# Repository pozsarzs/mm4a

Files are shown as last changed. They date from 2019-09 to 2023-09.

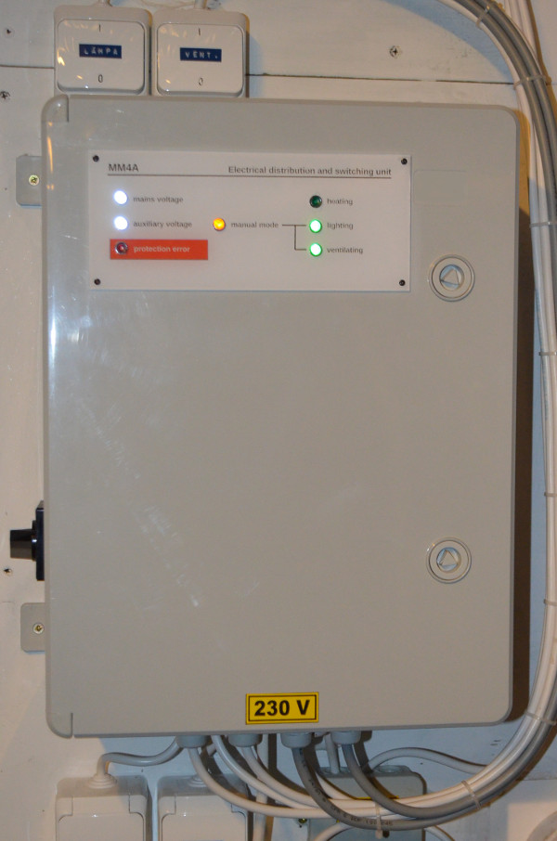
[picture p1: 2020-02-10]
pictures/mm4a.jpg

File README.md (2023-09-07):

**MM4A * Electrical distribution and switching unit for growing house**  
Copyright (C) 2019 Pozsár Zsolt <pozsarzs@gmail.com>  
Homepage: <http://www.pozsarzs.hu>  
GitHub: <https://github.com/pozsarzs/mm4a>

**Documentation**

- version:             1.0
- language:            en, hu
- licence:             CC-BY-NC-4.0

**Hardware**

 - version:            v190919

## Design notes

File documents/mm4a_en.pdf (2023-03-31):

## MM4A Electrical distribution and switching unit for growing house

### Technical manual

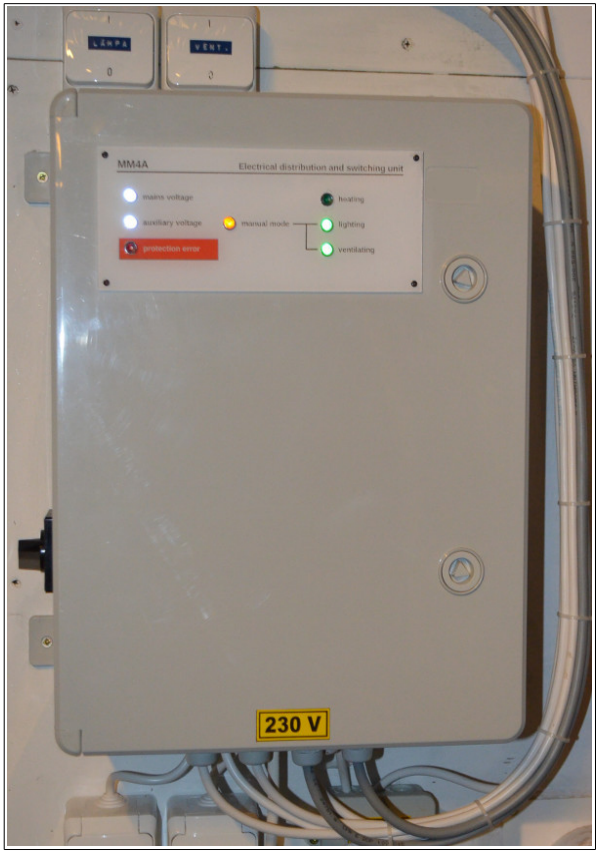
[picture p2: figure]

Hardware version: v190919
Technical manual version: v1.0 Issue date: 2019-09-19
Drawing number: 59/4/1-2

## CC-BY-NC-4.0

Technical manual | 2

Content

Technical manual | 3

## I. Equipment

Technical manual | 4

You can use this unit with MM3D or MM5D digital contol and remote device to switch heater, lighting and ventilating of growing house.

### 1. Technical data

Supply voltage: | 230 V AC 50/60 Hz
Auxiliary voltage: | 230 V AC
Max. supply current: | max. 16 A
Required protection: | 16 A fuse or overcurrent breaker
Isolation class: | Class I.
Mechanical size: | 300 x 400 x 170 mm
IP protection: | IP 54
IK protection: | IK 03
Material of cover: | termoplast (ABS)

Outputs

| Heating | Lighting | Ventilating | Outdoor lighting | Internal connector | Wall connector
Mode of ext. control* Max. output Protection of output Warning light of | with NO contact | | | overcurrent breaker | overcurrent breaker | overcurrent breaker
Contolled | yes | yes | yes | no | no | no
Manual control | no | yes | yes
External control | yes | yes | yes
Output voltage | 230 V AC | 230 V AC | 230 V AC | 230 V AC | 230 V AC | 230 V AC
current** | 10 A | 6 A | 6 A | 6 A | 6 A | 10 A
| overcurrent breaker | overcurrent breaker | overcurrent breaker
protection | yes | yes | yes | no | yes | no

* WARNING! There are 230 V AC between opened contacts!
**The value indicates the load capacity of a given branch, but the sum of the total output currents must not exceed the total current consumption of the device.

### 2. Description

a) Heating

The output of the channel is protected by a F4 circuit-breaker inside the cabinet, and its active status is indicated by the green LED marked Active. The channel cannot be operated manually, it can be

Technical manual | 5

activated by a short-circuit to its input. The external thermostat prevents overheating of the growing area due to a malfunction. The off contact disconnects the heaters from the mains (L-N).

The red light on the Protection error LED indicates overcurrent protection.

b) Lighting

The output of the channel is protected by an F5 circuit breaker inside the cabinet, and its active status is indicated by the green LED marked Active. The channel can be switched on manually and by a short circuit to its input. Manual mode is indicated by the yellow LED marked Manual mode. When the contactor is off, the lamps are disconnected from the mains (L-N).

The red light on the Protection error LED indicates overcurrent protection.

c) Ventilating

The output of the channel is protected by an F6 circuit breaker inside the cabinet, and its active status is indicated by the green LED marked Active. The channel can be switched on manually and by a short circuit to its input. Manual mode is indicated by the yellow LED marked Manual mode. When the contactor is off, the ventilators are disconnected from the mains (L-N).

The red light on the Protection error LED indicates overcurrent protection.

d) Outdoor lighting

The channel is used to supply the outside lighting of the growing house, this output is protected by a circuit breaker F1 located inside the cabinet.

e) Wall socket

The channel is used to power the wall socket inside the growing house, this output is protected by a circuit breaker F2 inside the cabinet.

f) Internal socket

The channel is used to supply the socket inside the enclosure and the control unit can be connected to it. The output is protected by F3 circuit breaker.

The red light on the Protection error LED indicates overcurrent protection.

### 3. Schematic and other drawings

The schematic of MM4A is shown in Annex 1, the wiring diagram is shown in Annex 2. This diagrams, drilling drawings and front foil can be downloaded from the developer / manufacturer's website as part of the complete documentation in a variety of formats.

### 4. Terms of use

Hardware documentation can be modified and/or redistributed under the Creativ Commons 4.0

Technical manual | 6

Attribution Non-Commercial (CC-BY-NC-4.0) License. You can read the full (English) text of the license online. (Refer to Chapter II for references.)

### 5. Look of the unit

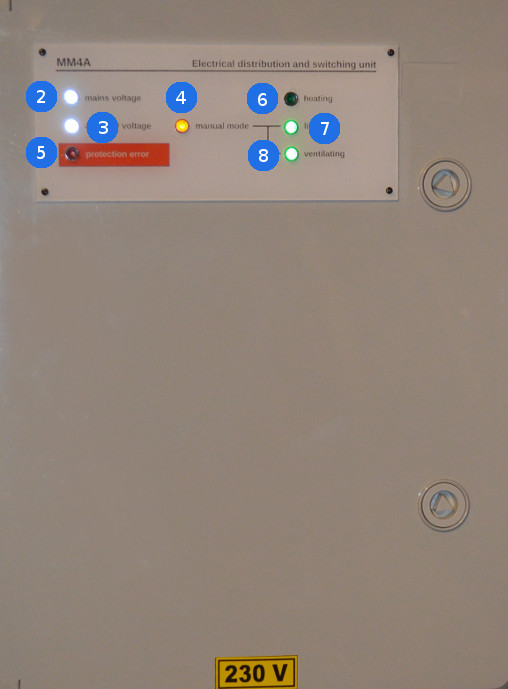
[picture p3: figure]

Figure 1: Front panel

Technical manual | 7
a) Manuals

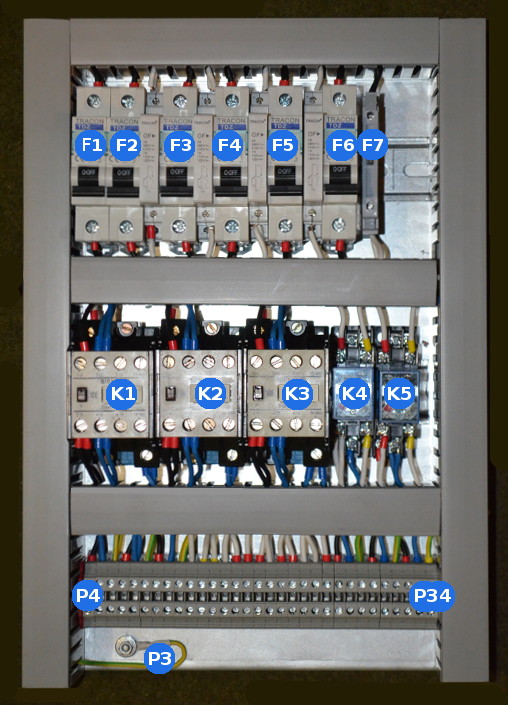
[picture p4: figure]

1: | Mains - Power switch
2: | Mains voltage - presence of mains voltage (white LED)
3: | Auxiliary voltage - the presence of auxiliary voltage (white LED)
4: | Manual mode - manual mode of lighting and ventilating (yellow LED)
5: | Protection error - status of overcurrent protection (red LED)
6: | Active - heater output is under voltage (green LED)
7: | Active - lighting output is under voltage (green LED)
8: | Active - ventilating output is under voltage (green LED)

Figure 2: Internal construction

Technical manual | 8
b) Connector pinout

P1: mains power - L (input terminal of power switch)
P2: mains power - N (input terminal of power switch)
P3: mains power - PE (screw connection on mounting plate) P4: outdoor lamp - L
P5: outdoor lamp - N
P6: outdoor lamp - PE
P7: wall socket - L
P8: wall socket - N
P9: wall socket - PE
P10: internal socket - L
P11: internal socket - N
P12: internal socket - PE
P13: signal output - common
P14: signal output - manual operation (NO relay contat) P15: signal output - protection error (NO relay contat) P16: heater control input - auxiliary voltage
P17: heater control input - from control unit
P18: heater control input - safety thermostat
P19: heater control input - safety thermostat
P20: lighting control input - auxiliary voltage
P21: lighting control input - manual switch
P22: lighting control input - from control unit and manual switch P23: ventilating control input - auxiliary voltage
P24: ventilating contol input - manual switch
P25: ventilating contol input - from control unit and manual switch P26: heater power output - L
P27: heater power output - N
P28: heater power output - PE
P29: lighting power output - L P30: lighting power output - N P31: lighting power output - PE P32: ventilating power output - L P33: ventilating power output - N P34: ventilating power output - PE

Technical manual | 9

### 6. Downloadable documentation

The complete hardware documentation can be downloaded from the manufacturer's website in a compressed file in .tar.gz format. (Refer to Chapter II for references.)

Name of package: mm4a-190919-1.0.tar.gz

Content of package - important files only:

mm4a
│
├───cad_files | | CAD files
│ | ├───connecting | | | connecting drawing (KiCAD)
│ | │ | connecting.pro | | | project file
│ | │ | connecting.sch | | | schematic
│ | │ | *.* | | | others
│ | │
│ | ├───drilling | | | drilling drawings (LibreCAD)
│ | │ | bottom.dxf | | | bottom of cover
│ | │ | front.dxf | | | front of cover
│ | │
│ | └───mm4a | | | MM4A unit (KiCAD)
│ | mm4a.pro | | project file
│ | mm4a.sch | | schematic
│ | *.* | | others
│
├───documents | | documentation
│ | drill_bottom.pdf | | drilling bottom of cover
│ | drill_front.pdf | | drilling front of cover
│ | manual-source.tar.gz | | source of manual
│ | mm4a_en.pdf | | Technical manual (EN)
│ | mm4a_hu.pdf | | Technical manual (HU)
│ | sch_connecting.pdf | | connection of unit
│ | sch_mm4a.pdf | | MM4A schematic
│
├───frontpage | | frontpage
│ | frontpage.eps | | frontpage
│ | frontpage.odg | | frontpage
│ | frontpage.svg | | frontpage
│ | preview.png | | preview of frontpage
│ | size.txt | | size of frontpage
│
├───pictures | pictures
│ | mm4a.jpg | look
│ | sch_connecting.svg | connection of unit
│ | sch_mm4a.svg | MM4A schematic
│
├───LICENCE | Terms of use (EN)
└───README | Short description (EN)

Technical manual | 10

## II. Related links

Technical manual | 11

### 1. Equipment

Full documentation | http://www.szerafingomba.hu/equipments/mm4a/mm4a-190919-1.0.tar.gz
Technical manual (EN) | http://www.szerafingomba.hu/equipments/mm4a/tech-manual-190919-1.0-en.pdf
Technical manual (HU) | http://www.szerafingomba.hu/equipments/mm4a/tech-manual-190919-1.0-hu.pdf

Schematic drawings:
MM4A (PDF) | http://www.szerafingomba.hu/equipments/mm4a/sch_mm4a.pdf
Connection (PDF) | http://www.szerafingomba.hu/equipments/mm4a/sch_mm4a-connecting.pdf

### 2. Terms of use

CC-BY-NC-4.0 (EN) | https://creativecommons.org/licenses/by-nc/4.0/legalcode
CC-BY-NC-4.0 (EN) | https://creativecommons.org/licenses/by-nc/4.0/
CC-BY-NC-4.0 (HU) | https://creativecommons.org/licenses/by-nc/4.0/deed.hu

### 3. Developer and manufacturer

Homepage | http://www.szerafingomba.hu
E-mail | info@szerafingomba.hu

Technical manual | 12

## III. Annexes

Technical manual | 13

### 1. Schematic drawings

1. MM4A schematic and list of materials
2. Connecting schematic and list of materials

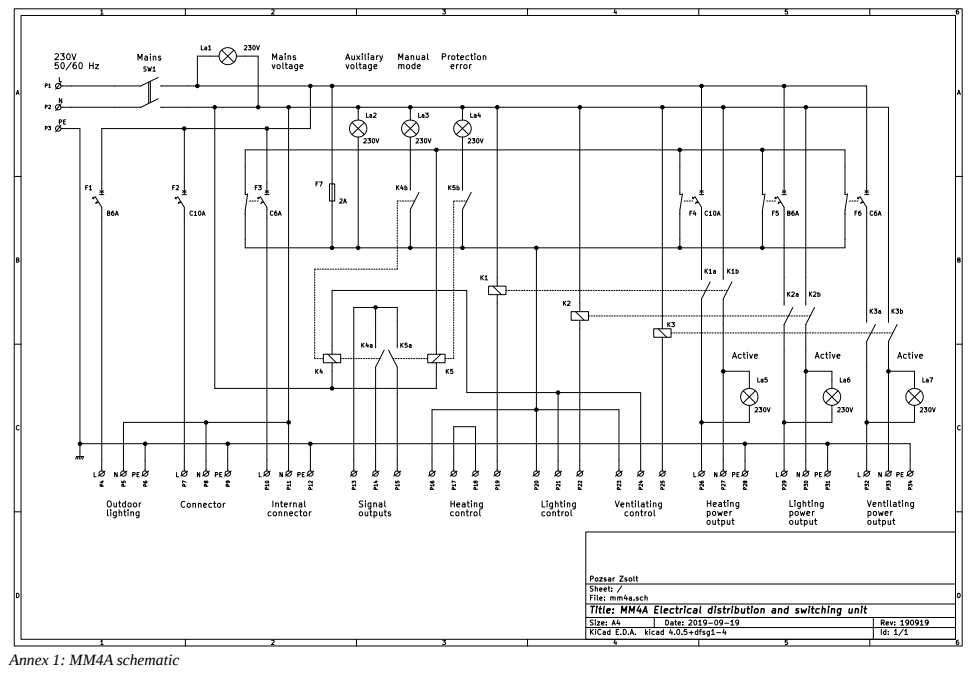
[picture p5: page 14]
Annex 1: MM4A schematic

List of materials

Pos. n. | Value | Description | Note | Pos. n. | Value | Description | Note
F1 | 6 A | overcurrent breaker B type | La5 | 230 V, green | signalling lamp
F2 | 10 A | overcurrent breaker C type | La6 | 230 V, green | signalling lamp
F3 | 6 A | overcurrent breaker C type | La7 | 230 V, green | signalling lamp
| 240 V/6 A | auxiliary contact | | P4-P34 | 0,5-6mm² | screw connectors
F4 | 10 A | overcurrent breaker C type | Sw1 | 250 V 16 A | two-pole switch
| 240 V/6 A | auxiliary contactor
F5 | 6 A | overcurrent breaker B type | 1 db | 300x400x170 | cabinet with mounting plate | ABS
| 240 V/6 A | auxiliary contact | | 2 m | 25x60 | wiring trunking
F6 | 6 A | overcurrent breaker C type | 1 m | 35 mm | mounting rail
| 240 V/6 A | auxiliary contact
F7 | 2 A | fuse
| 800 V/6,3 A | fuse holder
K1 | 230 V AC | contactor
K2 | 230 V AC | contactor | suitable for the load
K3 | 230 V AC | contactor
K4 | 230 V AC | relay | with two changeover
K5 | 230 V AC | contacts relay
La1 | 230 V, white | signalling lamp
La2 | 230 V, white | signalling lamp
La3 | 230 V, yellow | signalling lamp
La4 | 230 V, red | signalling lamp

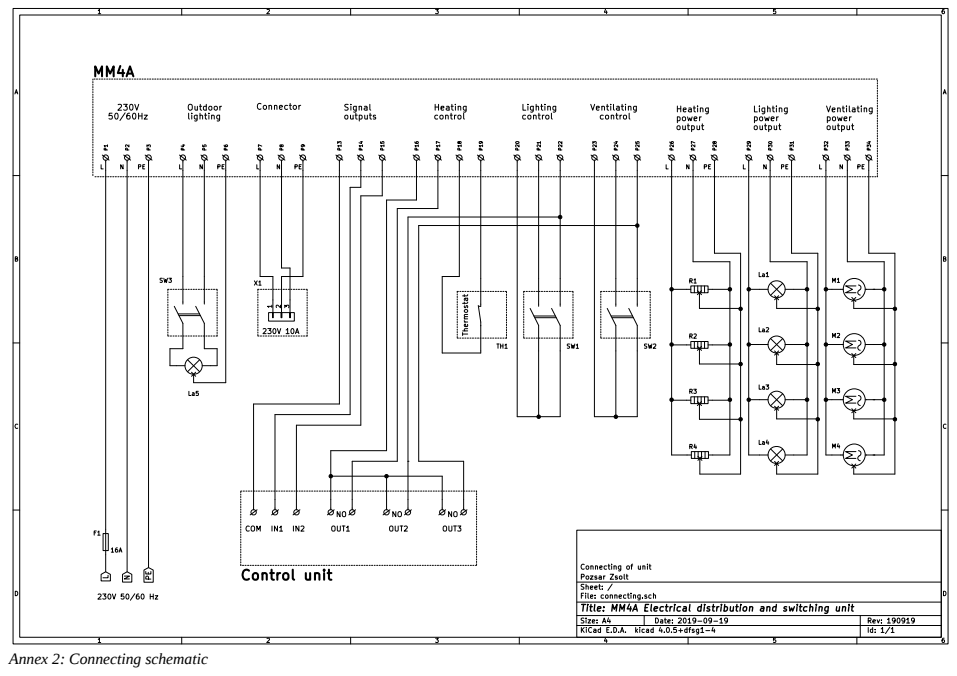
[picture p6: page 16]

Annex 2: Connecting schematic

List of materials

Pos. n. | Value | Description | Note | Pos. n. | Value | Description | Note
F1 | 16 A | fuse | or overcurrent breaker
La1-4 | 230 V AC | waterproof luminaires | as needed
La5 | 230 V AC | waterproof luminaire | as needed
R1-4 | 230 V AC | heaters | as needed
M1-4 | 230 V AC | ventilators | as needed
SW1 | 230 V AC | two-pole waterproof switch
SW2 | 230 V AC | two-pole waterproof switch
SW3 | 230 V AC | two-pole waterproof switch
TH1 | 230 V AC | thermostat with changeover
contact
X1 | 230 V/10 A | waterproof socket
| 230 V/6 A | swinging socket | for adaptor

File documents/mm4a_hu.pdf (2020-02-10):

## MM4A Termesztőházi elektromos elosztó- és kapcsolóberendezés

### Műszaki leírás


Hardver változat: v190919
Műszaki leírás változat: v1.0 Kibocsátás dátuma: 2019-09-19 Rajzszám: 59/4/1-1

## CC-BY-NC-4.0

Műszaki leírás | 2

Tartalomjegyzék

Műszaki leírás | 3

## I. A berendezés

Műszaki leírás | 4

A készülék kézi párásítású, hűtést nem igénylő termesztőhely elektromos fogyasztóinak kapcsolására alkalmas. Működtetéséhez az MM3D vagy az MM5D digitális vezérlő és távfelügyelő berendezés szükséges.

### 1. Műszaki adatok

Tápfeszültség: | 230 V AC 50/60 Hz
Segédfeszültség: | 230 V AC
Teljes áramfelvétel: | max. 16 A
Kiépítendő védelem: | 16 A biztosító vagy kismegszakító
Szigetelési osztály: | I. osztály
Mechanikai mérete: | 300 x 400 x 170 mm
IP védettség: | IP 54
IK védettség: | IK 03
Készülékház anyaga: | termoplaszt (ABS)

Kimenetek

| Fűtés | Világítás | Szellőztetés | Külső világítás | Belső dugalj | Fali dugalj
Külső vezérlés módja* Kimeneti Max. kimeneti Védelem | NO érintkezővel vezérelve
Vezérelt | igen | igen | igen | nem | nem | nem
Kézi vezérlés | nincs | van | van
Külső vezérlés | van | van | van
feszültség | 230 V AC | 230 V AC | 230 V AC | 230 V AC | 230 V AC | 230 V AC
áram** | 10 A | 6 A | 6 A | 6 A | 6 A | 10 A
Kimenet védelem | kismegszakító | kismegszakító | kismegszakító | kismegszakító | kismegszakító | kismegszakító
visszajelzés | van | van | van | nincs | van | nincs

* FIGYELEM! A nyitott érintkezők között 230 V AC mérhető!
**Az érték az adott ág terhelhetőségét adja meg, de a összes kimeneti áram összege nem haladhatja meg a készülék teljes áramfelvételét.

### 2. Ismertetés

a) Fűtés

A csatorna kimenete a készülékházon belül található F4 kismegszakítóval védett, az aktív állapotát

Műszaki leírás | 5

az Active feliratú zöld LED jelzi. A csatorna kézzel nem működtethető, a bemenetére adott rövidzárral kapcsolható be. A termesztőhely üzemzavar miatti túlfűtését a külső termosztát akadályozza meg. A kikapcsolt mágneskapcsoló a fűtőtesteket a hálózatról leválasztja (L-N).

A túláramvédelem kikapcsolt állapotát a Protection error feliratú LED piros fénye jelzi.

b) Világítás

A csatorna kimenete a készülékházon belül található F5 kismegszakítóval védett, az aktív állapotát az Active feliratú zöld LED jelzi. A csatorna kézzel és a bemenetére adott rövidzárral kapcsolható be. Kézi üzemmódot a sárga Manual mode feliratú LED jelzi. A kikapcsolt mágneskapcsoló a világítótesteket a hálózatról leválasztja (L-N).

A túláramvédelem kikapcsolt állapotát a Protection error feliratú LED piros fénye jelzi.

c) Szellőztetés

A csatorna kimenete a készülékházon belül található F6 kismegszakítóval védett, az aktív állapotát az Active feliratú zöld LED jelzi. A csatorna kézzel és a bemenetére adott rövidzárral kapcsolható be. Kézi üzemmódot a sárga Manual mode feliratú LED jelzi. A kikapcsolt mágneskapcsoló a ventillátorokat a hálózatról leválasztja (L-N).

A túláramvédelem kikapcsolt állapotát a Protection error feliratú LED piros fénye jelzi.

d) Külső világítás

A csatorna a termesztőház külső világításának táplálására szolgál, ez a kimenet készülékházon belül található F1 kismegszakítóval védett.

e) Fali dugalj

A csatorna a termesztőházon belül található fali dugalj táplálására szolgál, ez a kimenet készülékházon belül található F2 kismegszakítóval védett.

f) Belső dugalj

A csatorna a készülékházon belül található dugalj táplálására szolgál, a vezérlő berendezés ebbe csatlakoztatható. A kimenet készülékházon belül található F3 kismegszakítóval védett.

A túláramvédelem kikapcsolt állapotát a Protection error feliratú LED piros fénye jelzi.

### 3. Kapcsolási és egyéb rajzok

A készülék kapcsolási rajzát az 1. számú melléklet, a bekötését a 2. sz. melléklet tartalmazza. A kapcsolási rajzok, készülékház furatozási rajzai és az előlap nyomata a teljes dokumentáció részeként többféle formátumban letölthetők a fejlesztő/gyártó honlapjáról.

Műszaki leírás | 6

### 4. Felhasználási feltételek

A hardver dokumentációja a Creativ Commons 4.0 Attribution Non-Commercial (CC-BY-NC-
4.0) - „Nevezd meg!-Ne add el!” licenc alapján módosítható és/vagy terjeszthető. A licenc teljes (angol nyelvű) szövegét az interneten tudja elolvasni. (A hivatkozásokat a II. fejezetben találja.)

### 5. Kinézet


1. Ábra: Előlap

Műszaki leírás | 7


a) Kezelőszervek
1: | Mains - hálózati kapcsoló
2: | Mains voltage - hálózati feszültség megléte (fehér LED)
3: | Auxiliary voltage - segédfeszültég megléte (fehér LED)
4: | Manual mode - a világítás és a szellőztetés kézi üzemmódja (sárga LED)
5: | Protection error - a túláramvédelem állapota (piros LED)
6: | Active - a fűtés kimenete aktív (zöld LED)
7: | Active - a világítás kimenete aktív (zöld LED)
8: | Active - a szellőztetés kimenete aktív (zöld LED)
2. Ábra: Belső felépítés

Műszaki leírás | 8
b) Csatlakozók lábkiosztása

P1: hálózati táplálás - L (a hálózati kapcsoló bemeneti kapcsa)
P2: hálózati táplálás - N (a hálózati kapcsoló bemeneti kapcsa) P3: hálózati táplálás - PE (a szerelőlapon lévő csavaros kötés) P4: külső világítás - L
P5: külső világítás - N
P6: külső világítás - PE
P7: fali dugalj - L
P8: fali dugalj - N
P9: fali dugalj - PE
P10: belső dugalj - L
P11: belső dugalj - N
P12: belső dugalj - PE
P13: jelkimenet - közös
P14: jelkimenet - kézi üzemmód (NO relé érintkező) P15: jelkimenet - védelem hiba (NO relé érintkező) P16: fűtés vezérlő bemenet - segédfeszültég
P17: fűtés vezérlő bemenet - vezérelő egységtől P18: fűtés vezérlő bemenet - biztonsági termosztát P19: fűtés vezérlő bemenet - biztonsági termosztát
P20: világítás vezérlő bemenet - segédfeszültég
P21: világítás vezérlő bemenet - kézi kapcsoló
P22: világítás vezérlő bemenet - vezérelő egységtől és a kézi kapcsolótól P23: szellőztetés vezérlő bemenet - segédfeszültég
P24: szellőztetés vezérlő bemenet - kézi kapcsoló
P25: szellőztetés vezérlő bemenet - vezérelő egységtől és a kézi kapcsolótól P26: fűtés teljesítmény kimenet - L
P27: fűtés teljesítmény kimenet - N
P28: fűtés teljesítmény kimenet - PE
P29: világítás teljesítmény kimenet - L P30: világítás teljesítmény kimenet - N P31: világítás teljesítmény kimenet - PE P32: szellőztetés teljesítmény kimenet - L P33: szellőztetés teljesítmény kimenet - N P34: szellőztetés teljesítmény kimenet - PE

Műszaki leírás | 9

### 6. Letölthető dokumentáció

A hardver teljes dokumentációja .tar.gz formátumú tömörített fájlban letölthető a gyártó honlapjáról. (A hivatkozásokat a II. fejezetben találja.)

A letölthető csomag neve: mm4a-190919-1.0.tar.gz

A csomag tartalma - csak a fontosabb fájlok:

mm4a
│
├───cad_files | | | CAD fájlok
│ | ├───connecting | | | | bekötési rajz (KiCAD)
│ | │ | | connecting.pro | | | projekt fájl
│ | │ | | connecting.sch | | | kapcsolási rajz
│ | │ | | *.* | | | egyéb fájlok
│ | │
│ | ├───drilling | | | | furatozás (LibreCAD)
│ | │ | | bottom.dxf | | | dobozfenék
│ | │ | | front.dxf | | | doboz előlap
│ | │
│ | └───mm4a | | | | MM4A berendezés (KiCAD)
│ | mm4a.pro | | | projekt fájl
│ | mm4a.sch | | | kapcsolási rajzm
│ | *.* | | | egyéb fájlok
│
├───documents | | | dokumentáció
│ | drill_bottom.pdf | | | dobozfenék furatozása
│ | drill_front.pdf | | | doboz előlap furatozás
│ | manual-source.tar.gz | | | a leírás forrásfájljai
│ | mm4a_en.pdf | | | Műszaki leírás (angol)
│ | mm4a_hu.pdf | | | Műszaki leírás (magyar)
│ | sch_connecting.pdf | | | bekötési rajz
│ | sch_mm4a.pdf | | | MM4a kapcsolási rajz
│
├───frontpage | | | előlap
│ | frontpage.eps | | | előlap
│ | frontpage.odg | | | előlap
│ | frontpage.svg | | | előlap
│ | preview.png | | | előnézet
│ | size.txt | | | méret
│
├───pictures | | | képek
│ | mm4a.jpg | | | kinézet
│ | sch_connecting.svg | | | bekötési rajz
│ | sch_mm4a.svg | | | MM4a kapcsolási rajz
│
├───LICENCE | | felhasználási feltételek (angol)
└───README | rövid ismertető (angol)

Műszaki leírás | 10

## II. Kapcsolódó hivatkozások

Műszaki leírás | 11

### 1. A berendezés

Teljes dokumentáció | http://www.szerafingomba.hu/equipments/mm4a/mm4a-190919-1.0.tar.gz
Műszaki leírás (EN) | http://www.szerafingomba.hu/equipments/mm4a/tech-manual-190919-1.0-en.pdf
Műszaki leírás (HU) | http://www.szerafingomba.hu/equipments/mm4a/tech-manual-190919-1.0-hu.pdf

Kapcsolási rajzok:
MM4A (PDF) | http://www.szerafingomba.hu/equipments/mm4a/sch_mm4a.pdf
Bekötés (PDF) | http://www.szerafingomba.hu/equipments/mm4a/sch_mm4a-connecting.pdf

### 2. Felhasználási feltételek

CC-BY-NC-4.0 (EN) | https://creativecommons.org/licenses/by-nc/4.0/legalcode
CC-BY-NC-4.0 (EN) | https://creativecommons.org/licenses/by-nc/4.0/
CC-BY-NC-4.0 (HU) | https://creativecommons.org/licenses/by-nc/4.0/deed.hu

### 3. Fejlesztő és gyártó

Honlap | http://www.szerafingomba.hu
E-mail | info@szerafingomba.hu

Műszaki leírás | 12

## III. Mellékletek

Műszaki leírás | 13

### 1. Kapcsolási rajzok

1. MM4A kapcsolási rajz alkatrészjegyzékkel (2 lap)
2. Bekötési rajz alkatrészjegyzékkel (2 lap)

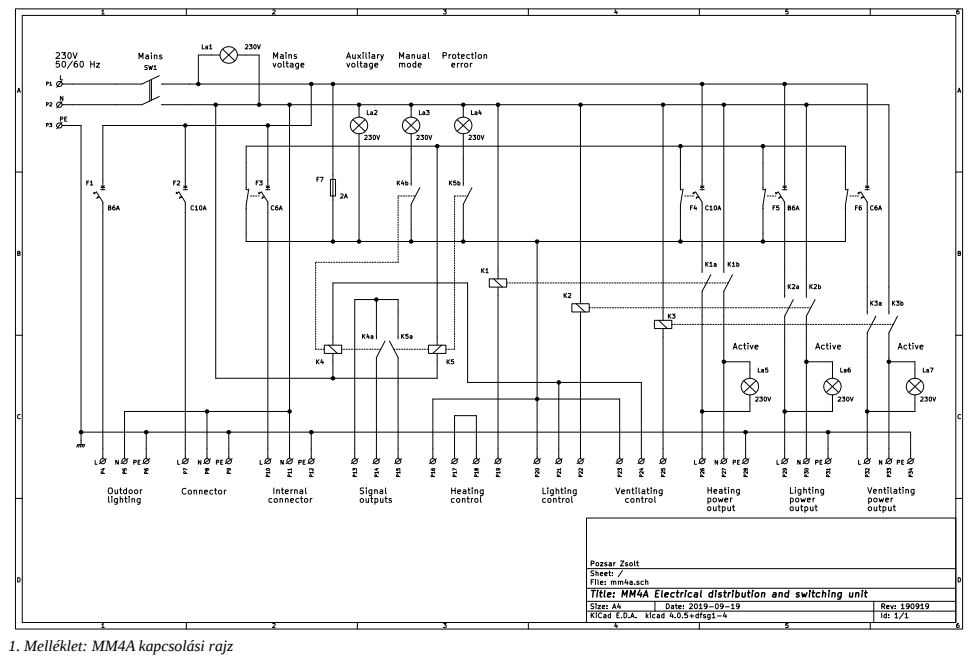
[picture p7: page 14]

1. Melléklet: MM4A kapcsolási rajz

Alkatrészjegyzék

Poz. sz. | Érték | Megnevezés | Megjegyzés | Poz. sz. | Érték | Megnevezés | Megjegyzés
F1 | 6 A | kismegszakító B típusú | La5 | 230 V, zöld | jelzőlámpa
F2 | 10 A | kismegszakító C típusú | | La6 | 230 V, zöld | jelzőlámpa
F3 | 6 A | kismegszakító C típusú | La7 | 230 V, zöld | jelzőlámpa
| 240 V/6 A | segédérintkező | | P4-P34 | 0,5-6mm² | ipari sorkapocs
F4 | 10 A | kismegszakító C típusú | | Sw1 | 250 V 16 A | kétpólusú kapcsoló
| 240 V/6 A | segédérintkező
F5 | 6 A | kismegszakító B típusú | 1 db | 300x400x170 | elosztószekrény szerelőlappal | ABS
| 240 V/6 A | segédérintkező | | 2 m | 25x60 | huzalozócsatorna
F6 | 6 A | kismegszakító C típusú | 1 m | 35 mm | sín
| 240 V/6 A | segédérintkező | | 11 db | M16 | tömszelence
F7 | 2 A | olvadóbiztosító
| 800 V/6,3 A | biztosíték foglalat
K1 | 230 V AC | mágneskapcsoló | terhelés szerint
K2 | 230 V AC | mágneskapcsoló | terhelés szerint
K3 | 230 V AC | mágneskapcsoló | terhelés szerint
K4 | 230 V AC | relé | két váltóérintkezővel
K5 | 230 V AC | relé | két váltóérintkezővel
La1 | 230 V, fehér | jelzőlámpa
La2 | 230 V, fehér | jelzőlámpa
La3 | 230 V, sárga | jelzőlámpa
La4 | 230 V, piros | jelzőlámpa

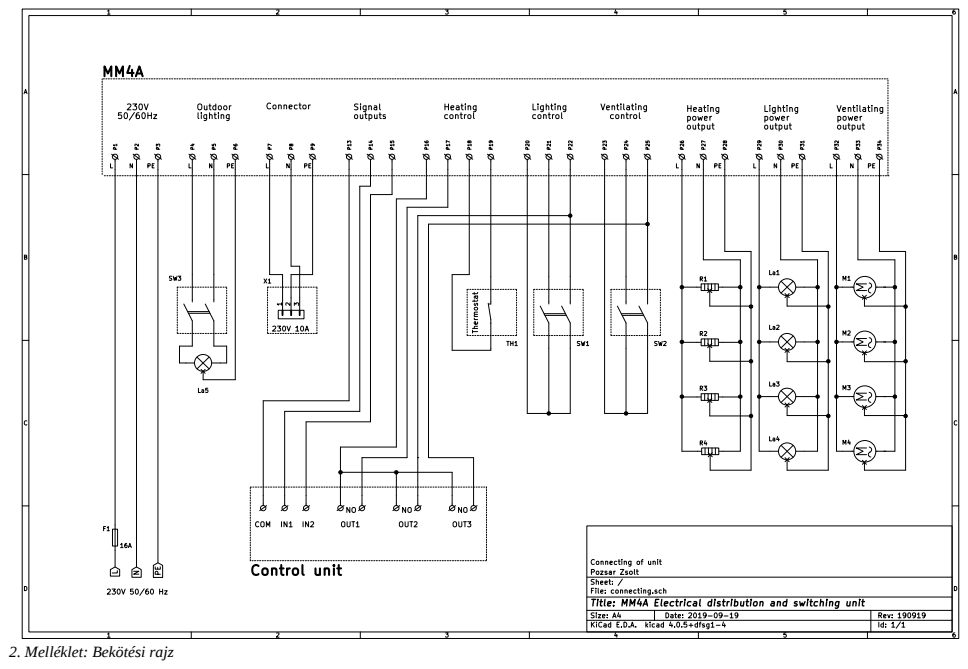
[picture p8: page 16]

2. Melléklet: Bekötési rajz

Alkatrészjegyzék

Poz. sz. | Érték | Megnevezés | Megjegyzés | Poz. sz. | Érték | Megnevezés | Megjegyzés
F1 | 16 A | olvadóbiztosító | vagy kismegszakító
La1-4 | 230 V AC | vízmentes lámpatest | igény szerint
La5 | 230 V AC | vízmentes lámpatest | igény szerint
R1-4 | 230 V AC | fűtőtest | igény szerint
M1-4 | 230 V AC | ventillátor | igény szerint
SW1 | 230 V AC | kétpólusú vízmentes kapcsoló
SW2 | 230 V AC | kétpólusú vízmentes kapcsoló
SW3 | 230 V AC | kétpólusú vízmentes kapcsoló
TH1 | 230 V AC | termosztát váltó- vagy bontóérintkezővel
X1 | 230 V/10 A | vízmentes dugalj
| 230 V/6 A | kétpólusú lengőalj | MM5D adapteréhez

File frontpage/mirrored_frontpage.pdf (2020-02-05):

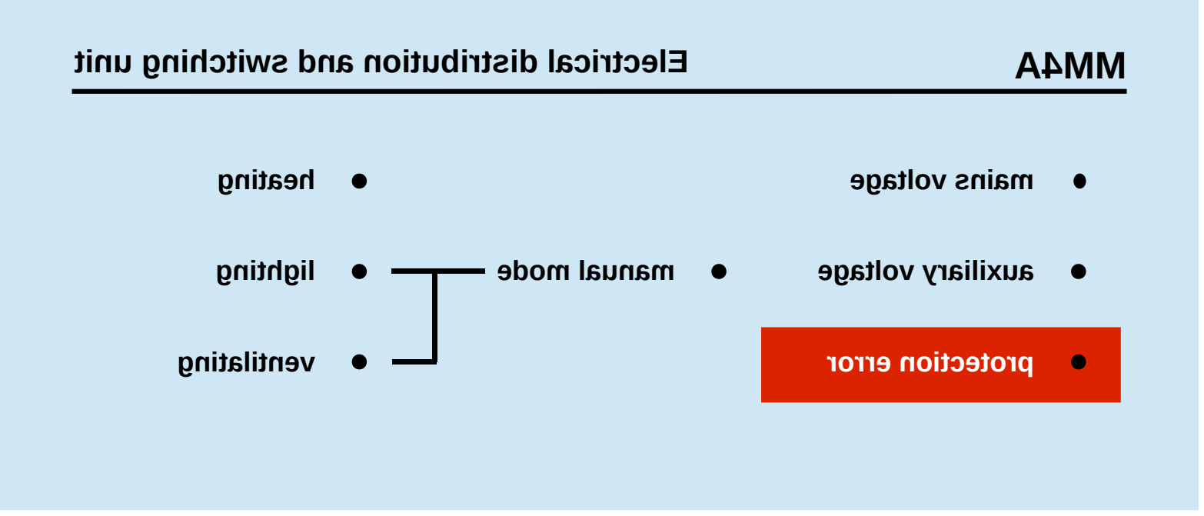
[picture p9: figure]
Electrical distribution and switching unit; heating mains voltage; lighting auxiliary voltage manual mode; ventilating protection error

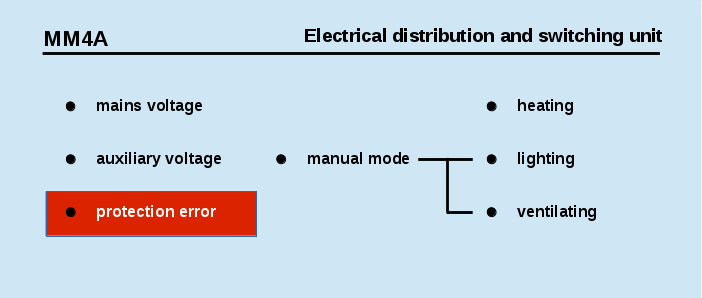
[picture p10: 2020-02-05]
frontpage/preview.png

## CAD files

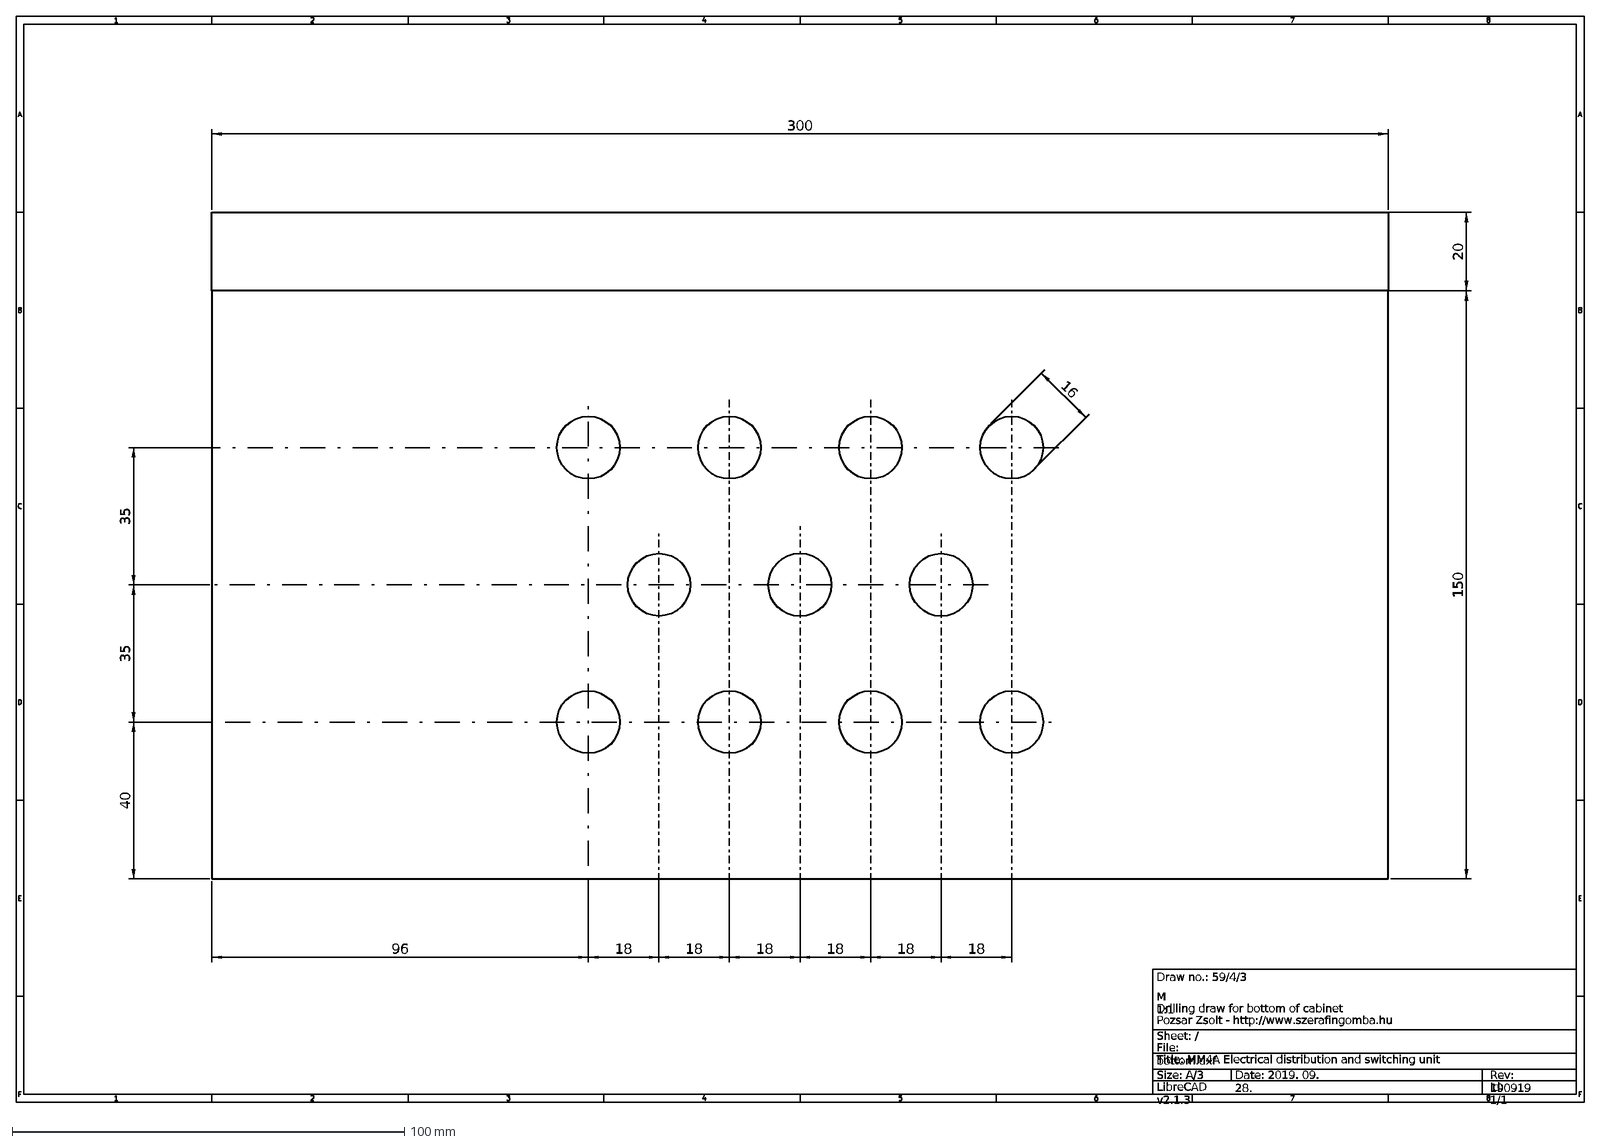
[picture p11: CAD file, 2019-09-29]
cad_files/drilling/bottom.dxf
150
20
300
40
35
96
18
16
LibreCAD v2.1.3
Size: A/3
File: bottom.dxf
Sheet: /
Title: MM4A Electrical distribution and switching unit
Draw no.: 59/4/3
Rev: 190919
Id: 1/1
Date: 2019. 09. 28.
M 1:1
Pozsar Zsolt - http://www.szerafingomba.hu
Drilling draw for bottom of cabinet

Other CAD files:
cad_files/drilling/front.dxf

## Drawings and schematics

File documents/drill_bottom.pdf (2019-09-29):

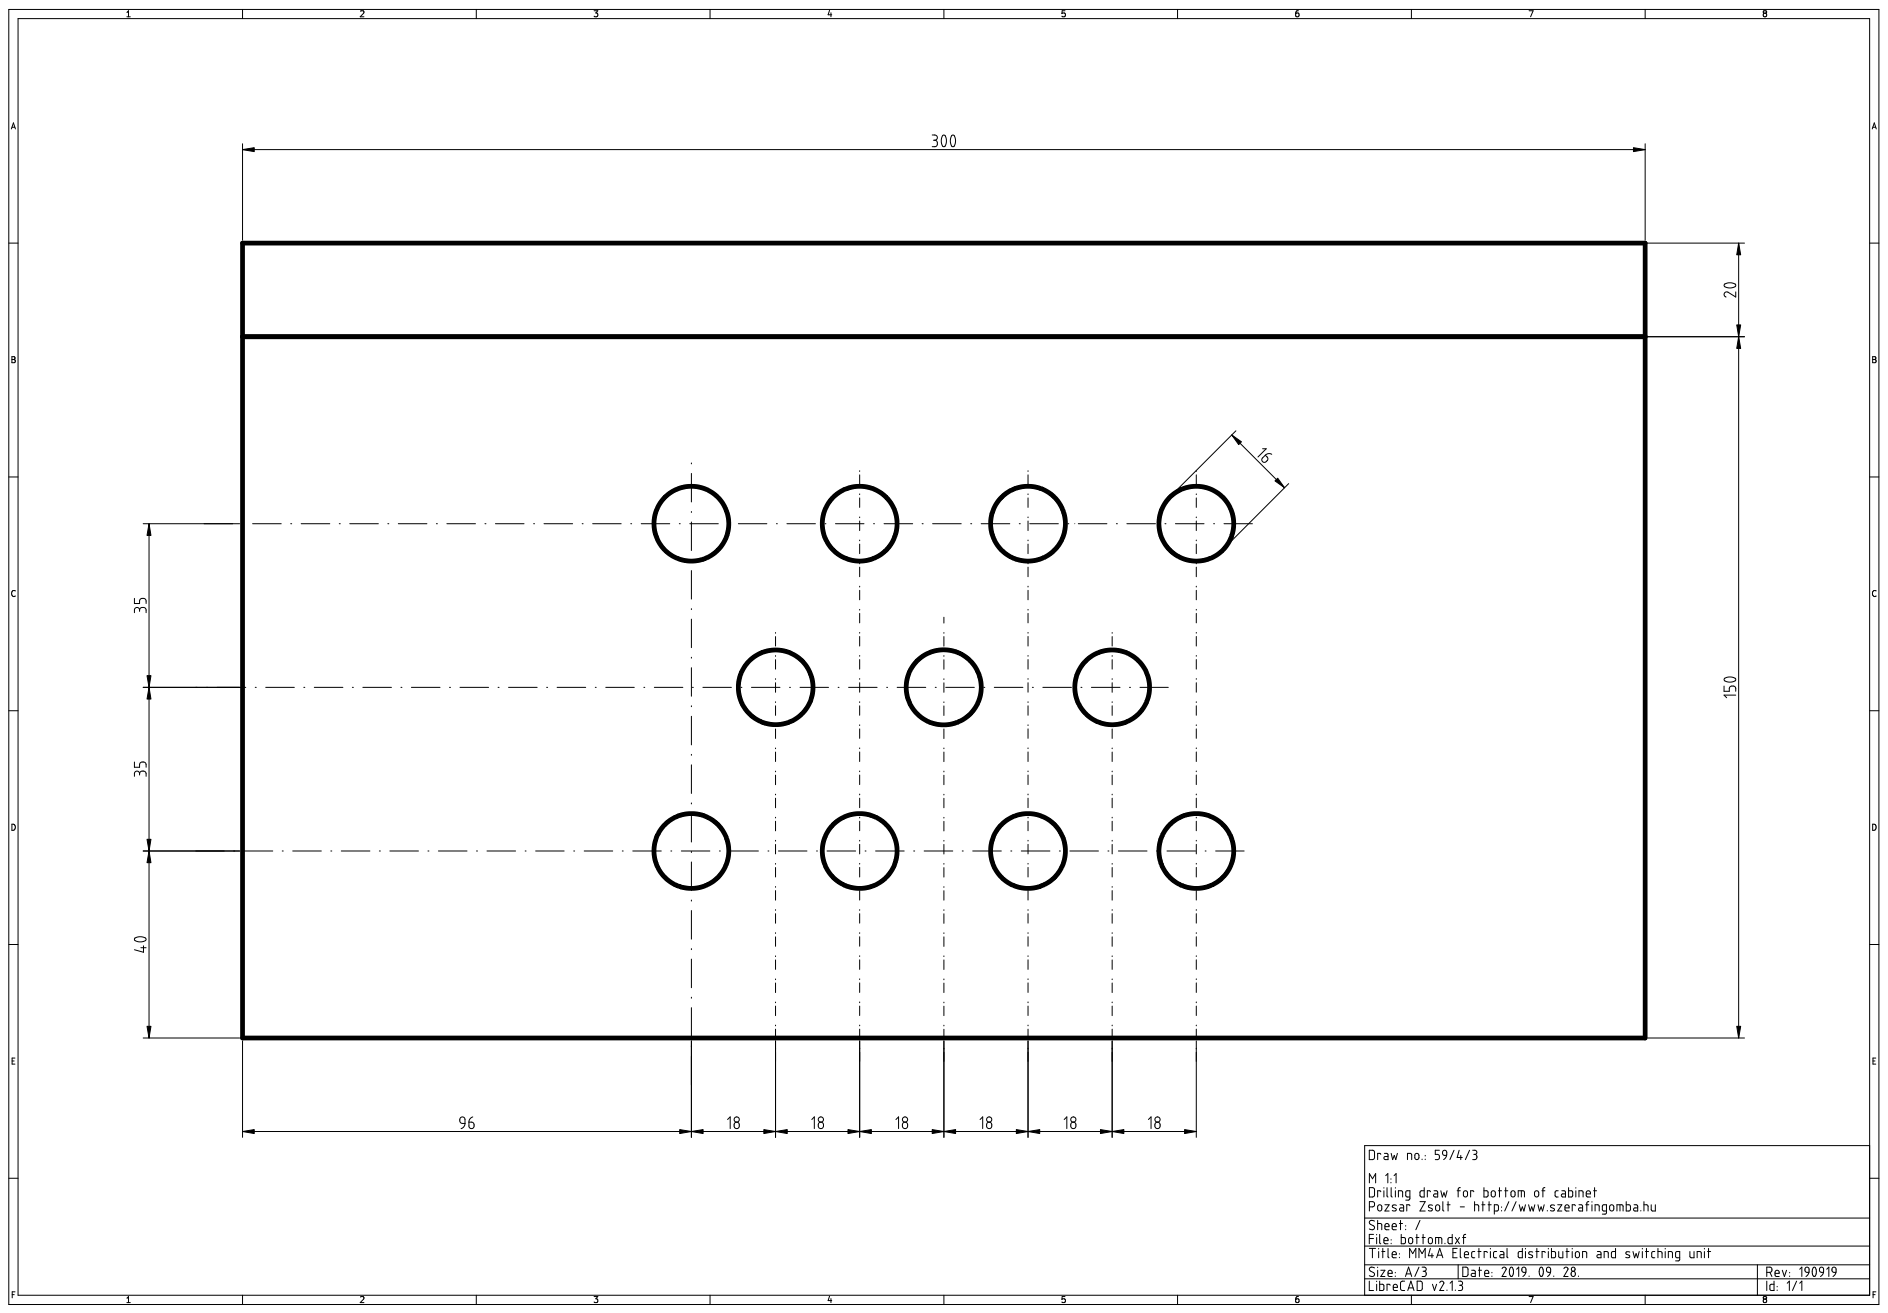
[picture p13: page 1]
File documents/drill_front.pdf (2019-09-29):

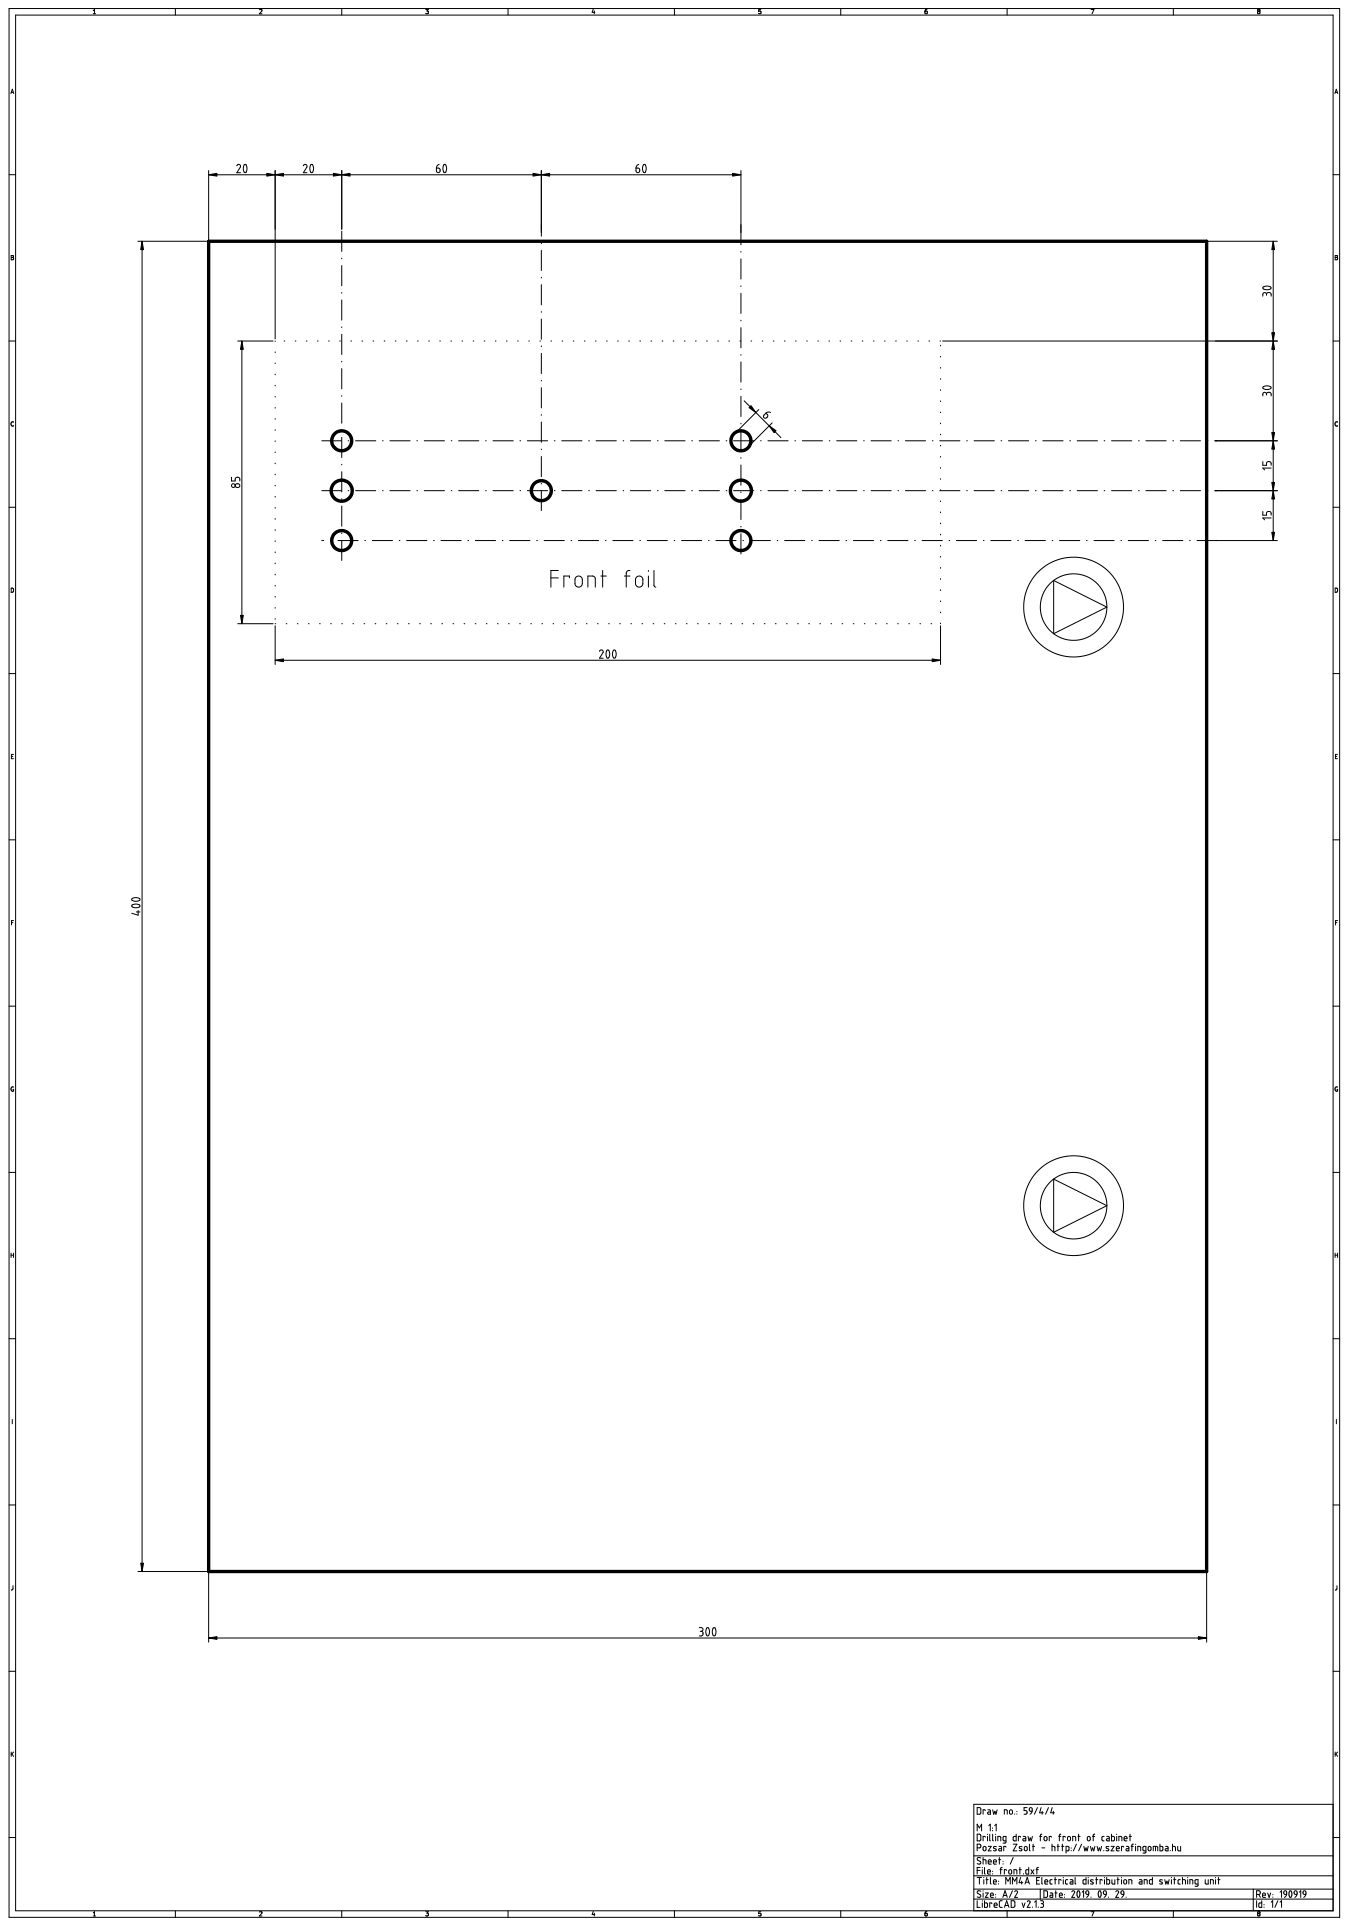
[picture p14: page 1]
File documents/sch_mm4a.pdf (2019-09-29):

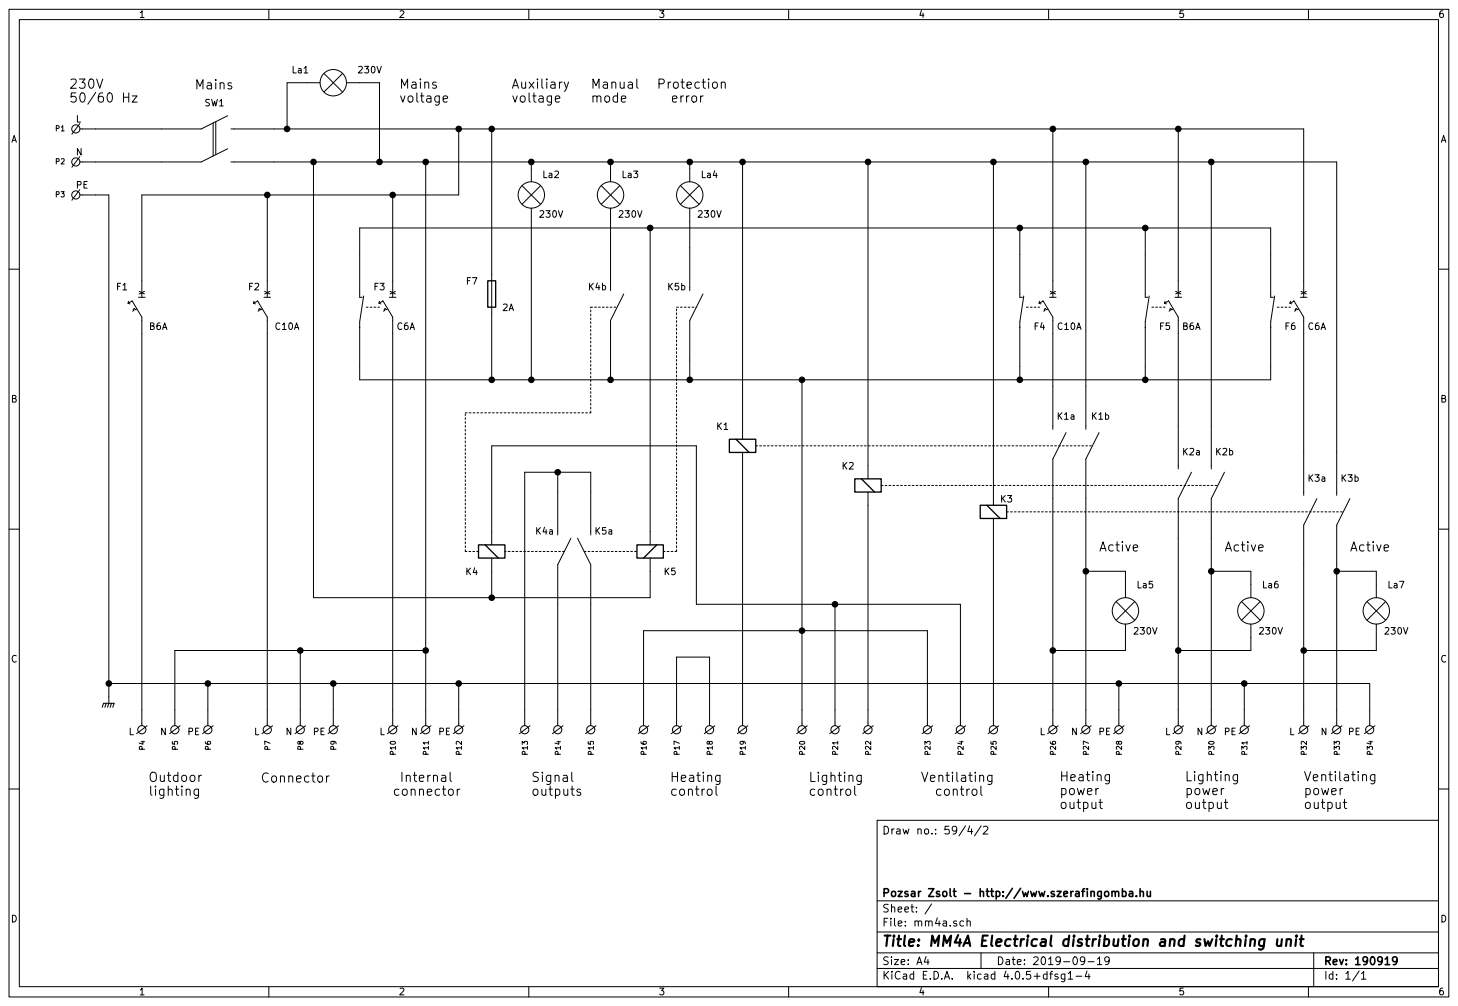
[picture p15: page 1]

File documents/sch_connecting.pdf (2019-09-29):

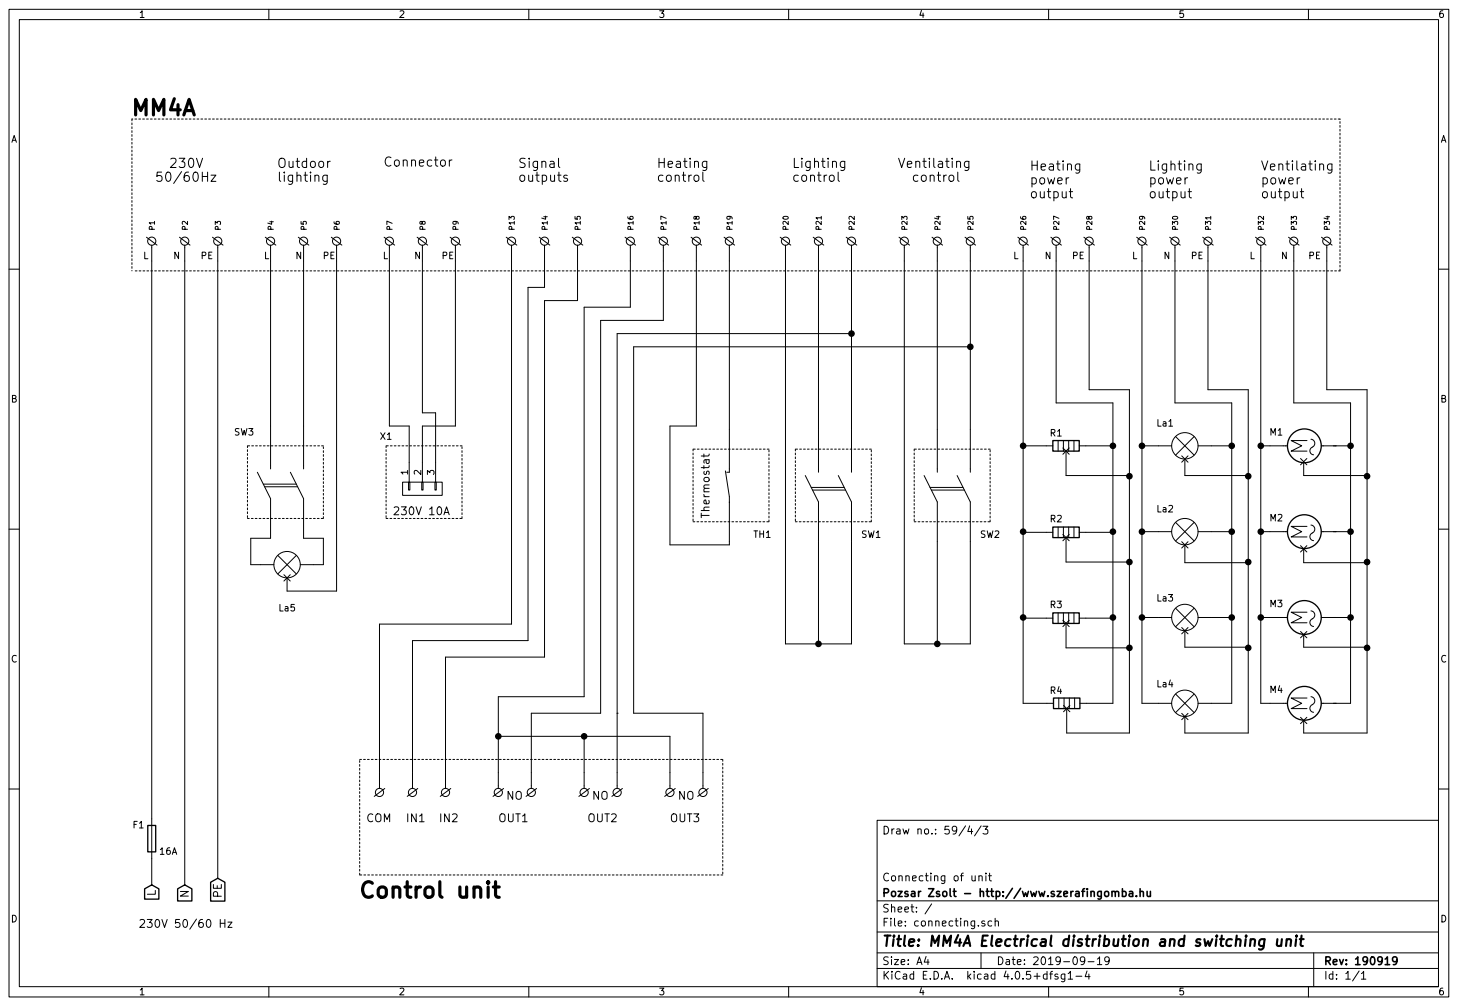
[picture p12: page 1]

File: connecting.sch Sheet: / Pozsar Zsolt - http://www.szerafingomba.hu

Id: 1/1 Title: MM4A Electrical distribution and switching unit
